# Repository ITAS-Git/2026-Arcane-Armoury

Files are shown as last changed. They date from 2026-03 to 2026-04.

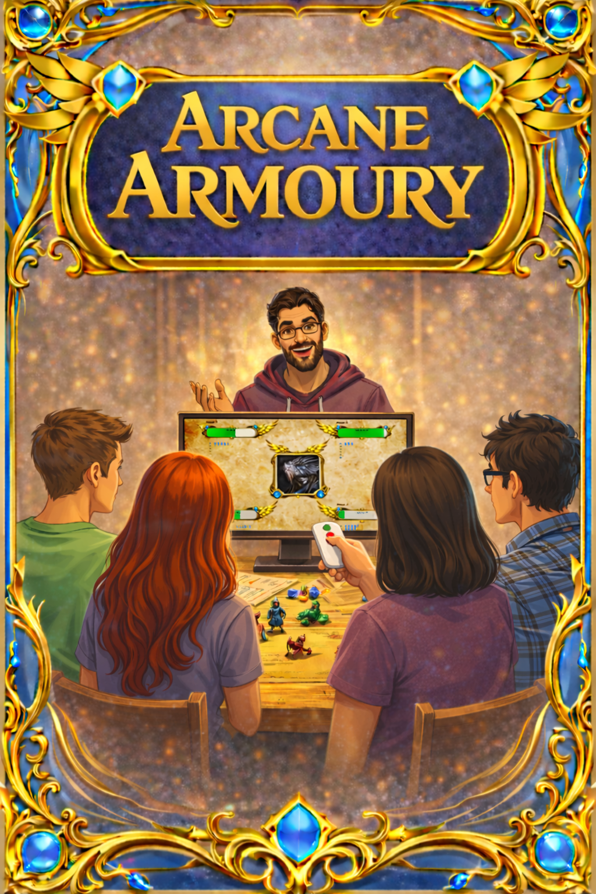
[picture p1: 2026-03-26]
arcane-armoury-poster.png

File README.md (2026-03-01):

# Arcane Armoury
Repository: 2026-Arcane Armoury
Organization: ITAS-Git
Course: ITAS Project Management (2026)

## Project Overview

The Arcane Armoury is a Raspberry Pi–based dual-screen encounter management tool designed to improve tabletop gameplay interaction and reduce paper dependency during sessions.

The system separates player-facing information from Dungeon Master controls using a two-display architecture:

- Player Screen (Public View): Displays HP, initiative order, and spell slots.
- DM Screen (Control Interface): Allows manual entry and editing of HP, initiative, and spell slots using mouse and keyboard.

Physical push buttons connected to Raspberry Pi GPIO allow players to increment or decrement HP without interrupting gameplay.

## Project Purpose

The purpose of this project is to:

- Increase player interaction by centralizing visible game data
- Provide a clean and readable interface for HP, initiative, and spell slot tracking
- Separate player and DM responsibilities through controlled interfaces
- Demonstrate integration of hardware (GPIO), backend software (Flask/SQLite), and frontend UI
- Apply Agile project management practices using GitHub Issues and Kanban

## Team Members
- Alexander Preston
- Brayden Burton
- Carter Ottenbreit

## System Architecture

Hardware:
- Raspberry Pi (dual HDMI output)
- 10-inch player-facing display
- Secondary DM display
- Momentary push buttons (HP increment/decrement)
- Supporting wiring and breadboard

Software:
- Python
- Flask (backend API)
- SQLite (database)
- HTML/CSS/JavaScript (frontend)
- Raspberry Pi OS

## Environments

### Main Display / Server
Install dependencies:
pip install -r requirements.txt

### Raspberry Pi Hardware
Install dependencies:
pip install -r requirements-pi.txt

## Core Features

1. Dual-Screen Architecture
   - Public read-only player display
   - Interactive DM dashboard

2. HP Tracking
   - Player-controlled via physical buttons
   - DM manual override via dashboard

3. Initiative Tracking
   - DM-managed ordering
   - Real-time update to player screen

4. Spell Slot Tracking
   - Per-character slot levels
   - Spend and restore controls
   - Automatic validation (no negative or overflow values)

## Folder Structure

The repository follows this structure:

/app
    /static
        /css
        /js
    /templates
    app.py
    models.py
    routes.py

/documentation
    Project_Charter.pdf
    Scope_Statement.pdf
    WBS.xlsx
    Risk_Register.xlsx
    Meeting_Notes/
    Diagrams/

/hardware
    Wiring_Diagram.png
    GPIO_Map.pdf
    Parts_List.xlsx

/tests
    test_api.py

README.md

All documentation artifacts will be stored in the documentation folder and updated throughout the semester.

## Development Process

The team follows an iterative Agile workflow:

1. Issues created for each user story
2. Tasks broken into actionable checklist items
3. Priorities and size estimates assigned
4. Issues added to Kanban board
5. Work selected for 3-week sprint
6. Artifacts committed continuously to repository

## Repository Rules

- Every artifact (code, documentation, diagrams) must be committed.
- Clear commit messages are required.
- All team members have full privileges.

## License

Academic project for ITAS coursework.

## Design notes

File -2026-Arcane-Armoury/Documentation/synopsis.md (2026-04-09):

# Arcane Armoury Project Synopsis

## Push 1 — Project Leader: Alex

During that time we completed:
- The initial frontend on the programming front.
- Set up a functioning project on GitHub.
- Initial research and set up of the Raspberry Pi.

## Push 2 — Project Leader: Carter

During that time we completed:
- Most of the programming front excluding any aspects related to the remote.
- Fully integrated GitHub into the Raspberry Pi.
- Fully added the first version of the program for testing on the Raspberry Pi.
- Begun initial research into ESP 32 for Bluetooth purposes.
- Began making the initial version of the remote.

## Push 3 (Final) — Project Leader: Brayden

During that time we completed:
- Research into Breadboards and Bluetooth.
- Implemented the program to have Bluetooth functionality.
- ESP 32 final coding and final program version.
- Creating the shell for the remote and in doing so completing the remote.

## Initial Version of the Project

Originally we wanted to create the project to be used on a laptop and have it display onto a TV, projector, or anything larger in scale. This idea was later abandoned and the project ended up being a Raspberry Pi connected to dual monitors, as using a laptop would cause problems later on and securing a large TV or projector would also be hard to acquire for the purposes of a single project.

## Potential Future Improvements

Things we later thought to add after project completion that would improve the overall project should we choose to continue it after semester's end:

- **Power Switch for the Raspberry Pi** — Currently, the system requires manual steps to start up. We intended to implement a cleaner boot process or physical switch to make powering on and off more seamless for users at the table.
- **Background Music** — We had planned to integrate ambient background music into the player-facing display to enhance immersion during sessions. The feature was scoped out due to time constraints and was not implemented in the final build.

## Lessons Learned

This project taught us valuable lessons, including:

- **Communication** is far more critical than it first appears in a larger, multi-component project. As the system grew more complex, clear and timely communication between team members became essential to avoiding duplicated effort and cascading bugs.
- **Git and GitHub** are invaluable tools. Using issues, commit history, and the Kanban board kept the team aligned and gave everyone visibility into what was being worked on at any time.
- **Sticking to the defined scope** is harder than expected, especially when new ideas or improvements become apparent mid-project. Learning to evaluate whether a new idea is worth the scope risk is a skill we all developed over the course of this project.

## Good Points

- **The Bluetooth Remote** — The ESP32 BLE remote successfully communicated with the Raspberry Pi, giving players a physical way to interact with the system without breaking immersion at the table.
- **3D Printed Shell Casing** — The custom-printed enclosure gave the remote a polished, professional look and protected the breadboard components during use.

## Drawbacks

- **Startup Process** — The Raspberry Pi requires manual steps to bring the system online. A cleaner boot experience would make the system more accessible for non-technical users at the table.

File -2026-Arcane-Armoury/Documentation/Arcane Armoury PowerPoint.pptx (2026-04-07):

## A Dungeons and Dragons Program

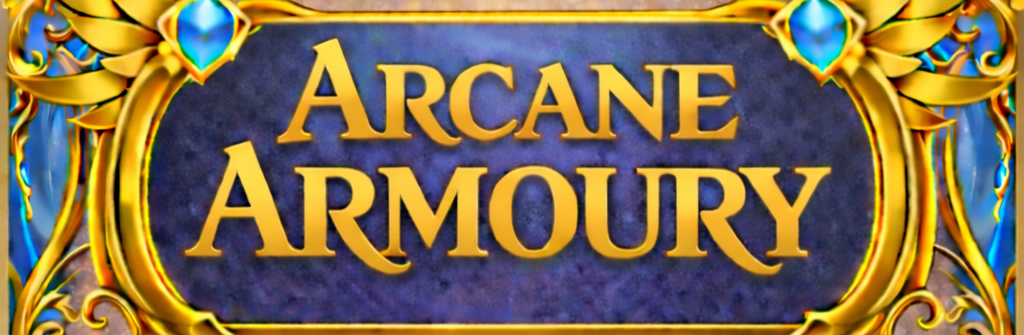
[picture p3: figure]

## Agenda

Members
The Arcane Armoury Project
Scope
Tech Stack
Demo
The Good Things
Challenges
Lessons learned

## The Members of the Arcane Armoury Project

1. Backend coder
2. Troubleshooting

Alex

1. Frontend coder
2. Remote
3. Poster

Carter

Brayden

1. ESP 32U coder
2. 3D design
3. 3D Printing
4. Remote
5. Raspberry pi setup

## The Arcane Armoury Project

- The idea of the project is to have a dual monitor setup, one monitor for the Dungeon Master and one monitor for the Players to view.
- The purpose of this is to have a digital semi-interactable interface for players to actively engage in as a group.
- This project is set up on a Raspberry Pi 4, alongside a remote made using a breadboard and an ESP 32U, as well as two monitors.

## Scope of Arcane Armoury Project

- The primary program
- An interface for the Dungeon Master to have the ability to change the background, character portraits, and player turns.
- A remote controller for players to be able to raise and lower the state of their current Health points

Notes: The primary program that would be responsible for the majority of the project's functionality.

An interface for the Dungeon Master to have the ability to change the background, character portraits, and player turns.

A remote controller for players to be able to raise and lower the state of their current Health points

A 3D printed shell casing for the remote controller.

## The Tech Stack

- A program that uses python, java script, HTML, and CSS
- A remote controller using breadboard components and Bluetooth
- A 3D printed shell casing for the remote controller.
- Dual Monitors
- A single Raspberry Pi 4

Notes: Allow us to demonstrate the final product

## Demo Time

## The Good Things

GitHub
The ESP 32U/Bluetooth
Communication

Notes: Thanks to GitHub’s ability to create issues for all members of the team to see, it made communication on the various issues during production far easier to diagnose and assess.

The ESP 32U/Bluetooth functionality was surprisingly simpler than we originally anticipated having to only add a few more lines of code to make it compatible with the current version of the program.

Communication initially was semi lacking, and it occurred to us all during the project how vital and instrumental communication can be during larger more complex projects.

## The Challenges

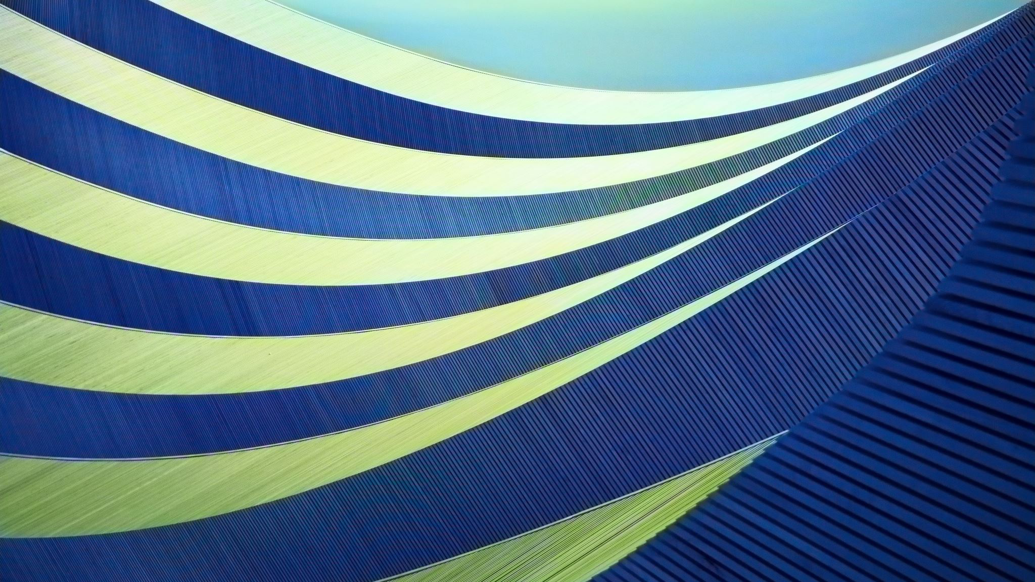
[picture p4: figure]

The Remote
The Primary Program

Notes: One of the bigger issues we faced was on the remote aspect on the project. For unknown reasons at the time one of the buttons failed to operate. This proved to be very challenging as it took quite some time to diagnose the core issue responsible for the malfunction.

The primary program proved to have its own set of challenges, the moment you would fix a single issue another would rise and take its place such as lining up the health bars on the HTML aspect, the printing of the remote shell, and various other issues that we did not originally anticipate would be major issues.

## Lessons learned

Proper communication
Sticking to the project scope

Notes: As previously stated, proper communication was far more valuable than originally anticipated. It was a hard lesson to accept but one we had to adapt to nonetheless

Sticking to the project scope can sometimes be difficult, especially when later down the line you think of various ways to improve things at the cost of going off scope.

## Thank you!

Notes: We learned largely about the importance of communication, the various services offered freely on GitHub, how to create functioning technical objects using Breadboards, as well as large number of things related to programming.

Ultimately the project was a challenge but one we will be better prepared for next time such a challenge arises.

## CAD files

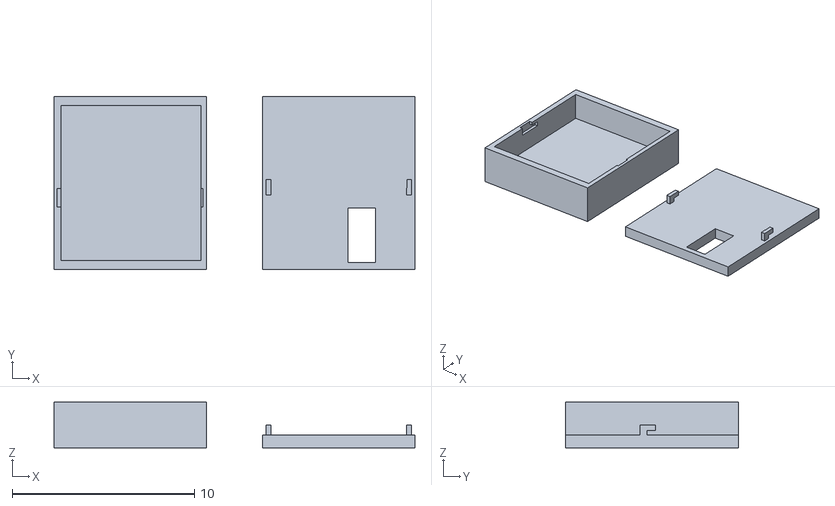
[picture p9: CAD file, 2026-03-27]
3d-designs/button_case.stl
19.8 x 9.52 x 2.50

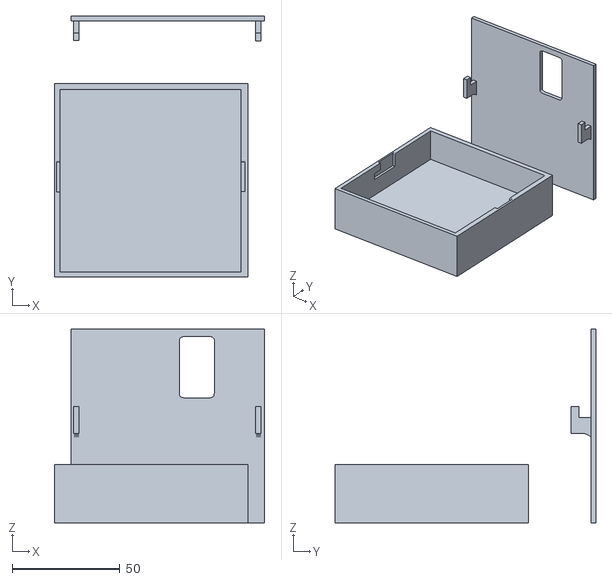
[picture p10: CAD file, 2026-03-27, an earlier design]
3d-designs/button_case(3).stl
97.6 x 121.3 x 90.0

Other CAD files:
3d-designs/button_case(1).stl
3d-designs/button_case(2) (1).stl
3d-designs/button_case(2).stl

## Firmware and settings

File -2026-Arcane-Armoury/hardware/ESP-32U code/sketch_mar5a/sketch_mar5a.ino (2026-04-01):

/**
 * Arcane Armory – ESP32 BLE Button Controller
 *
 * Sends BLE notifications to the Python bridge when UP or DOWN
 * buttons are pressed.
 *
 * Notification format: "+1" or "-1"
 *
 * UUIDs must match SERVICE_UUID / CHAR_EVENT_UUID in gpio_hp.py.
 *
 * Author: Alexander Preston
 * Course: ITAS 164
 */

#include <BLEDevice.h>
#include <BLEServer.h>
#include <BLEUtils.h>
#include <BLE2902.h>

// ---------------------------
// DEVICE CONFIG
// ---------------------------
#define DEVICE_NAME  "ArcaneArmory-P1"

// ---------------------------
// BLE UUIDs — must match gpio_hp.py
// ---------------------------
#define SERVICE_UUID  "8f3a2f10-6c5f-4c3d-a9a0-111111111111"
#define CHAR_UUID     "8f3a2f11-6c5f-4c3d-a9a0-222222222222"

// ---------------------------
// GPIO PINS
// ---------------------------
const int BUTTON_UP   = 19;
const int BUTTON_DOWN = 15;

// ---------------------------
// DEBOUNCE
// ---------------------------
const unsigned long DEBOUNCE_MS = 50;

int lastUpState = HIGH;
int lastDownState = HIGH;
unsigned long lastUpTime = 0;
unsigned long lastDownTime = 0;

// ---------------------------
// BLE STATE
// ---------------------------
BLECharacteristic* pCharacteristic = nullptr;
bool deviceConnected = false;

// Restart advertising when a client disconnects
class ArmoryServerCallbacks : public BLEServerCallbacks {
  void onConnect(BLEServer* pServer) override {
    deviceConnected = true;
    Serial.println("[BLE] Client connected");
  }

  void onDisconnect(BLEServer* pServer) override {
    deviceConnected = false;
    Serial.println("[BLE] Client disconnected, restarting advertising");
    delay(500);
    pServer->startAdvertising();
  }
};

// ---------------------------
// HELPERS
// ---------------------------

void sendNotify(const char* msg) {
  if (!deviceConnected || pCharacteristic == nullptr) {
    Serial.print("[BLE] Not connected, dropped: ");
    Serial.println(msg);
    return;
  }

  pCharacteristic->setValue((uint8_t*)msg, strlen(msg));
  pCharacteristic->notify();

  Serial.print("[BLE] Sent: ");
  Serial.println(msg);
}

void sendDelta(int delta) {
  char msg[4];
  snprintf(msg, sizeof(msg), "%+d", delta);  // "+1" or "-1"
  sendNotify(msg);
}

// ---------------------------
// SETUP
// ---------------------------
#include "esp_gap_ble_api.h"

void setup() {
  Serial.begin(115200);

  BLEDevice::init(DEVICE_NAME);

  //Increase BLE transmit power (MAX)
  esp_ble_tx_power_set(ESP_BLE_PWR_TYPE_DEFAULT, ESP_PWR_LVL_P9);
  esp_ble_tx_power_set(ESP_BLE_PWR_TYPE_ADV, ESP_PWR_LVL_P9);
  esp_ble_tx_power_set(ESP_BLE_PWR_TYPE_SCAN, ESP_PWR_LVL_P9);

  pinMode(BUTTON_UP, INPUT_PULLUP);
  pinMode(BUTTON_DOWN, INPUT_PULLUP);



  BLEServer* pServer = BLEDevice::createServer();
  pServer->setCallbacks(new ArmoryServerCallbacks());

  BLEService* pService = pServer->createService(SERVICE_UUID);

  pCharacteristic = pService->createCharacteristic(
    CHAR_UUID,
    BLECharacteristic::PROPERTY_NOTIFY
  );
  pCharacteristic->addDescriptor(new BLE2902());

  pService->start();

  BLEAdvertising* pAdvertising = BLEDevice::getAdvertising();
  pAdvertising->addServiceUUID(SERVICE_UUID);
  pAdvertising->setScanResponse(true);
  pAdvertising->start();

  Serial.print("[BLE] Advertising as: ");
  Serial.println(DEVICE_NAME);
}

// ---------------------------
// LOOP
// ---------------------------
void loop() {
  unsigned long now = millis();

  int upState = digitalRead(BUTTON_UP);
  int downState = digitalRead(BUTTON_DOWN);

  if (upState == LOW && lastUpState == HIGH) {
    if (now - lastUpTime >= DEBOUNCE_MS) {
      sendDelta(+1);
      lastUpTime = now;
    }
  }
  lastUpState = upState;

  if (downState == LOW && lastDownState == HIGH) {
    if (now - lastDownTime >= DEBOUNCE_MS) {
      sendDelta(-1);
      lastDownTime = now;
    }
  }
  lastDownState = downState;

  delay(5);
}

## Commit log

2026-02-27 Added code for websocket and more button inputs
2026-03-01 Add .gitignore and remove environment files, as well as added code for the bluetooth added buttons
2026-03-04 Fixed hp/slot delta events don't re-broadcast when the pi sends a button press
2026-03-04 Added sys.path insertion so it runs correctly as both python create_db.py and python -m package.create_db.
2026-03-04 Added CheckConstraint('slot_level BETWEEN 1 AND 9') to SpellSlot.
2026-03-04 feat: add server-side state cache and push to new socket connections on connect
2026-03-04 fix: add socket lifecycle logging and request state on connect for real-time sync
2026-03-25 switch SocketIO async_mode from threading to eventlet for proper WebSocket support
2026-03-27 added a file of the 3d designs, the current design is button_case(3).stl
    [button_case(1).stl, button_case(2) (1).stl, button_case(2).stl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]
2026-04-01 fixed bugg where Apply Button overwrote the manual buttons
2026-04-07 edited the power point
